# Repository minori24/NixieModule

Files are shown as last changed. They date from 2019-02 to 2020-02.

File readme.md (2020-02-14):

# nix module: miniature nixie tube driver modules

## nix module(仮)
nix moduleはニキシー管の制御に必要な部品を2x4cmの小さな基板に詰め込んだモジュールです。高圧電源の制御や煩雑なダイナミック点灯のコードを考える必要もなく、マイコンとI2Cで接続するだけでニキシー管の制御が可能です。Arduinoライブラリと組み合わせることでシンプルにニキシー管を点灯させることができます。

最大16桁をI2C経由で連結させ、各桁を独立して制御できます。すべての数字でフェードイン・フェードアウト、シャッフルなどのエフェクトが可能です。またRGB LEDによるバックライトもついています。

## Features
- 2x4cm
- I2Cインタフェース(プルアップ抵抗実装済み)
- ハードウェアPWM制御
- RGBバックライト(WS2812B互換 SK6812mini)
- スタティック点灯でシンプルな回路構成

## Arduino Library
ライブラリは[こちら](https://github.com/minori24/Lib_Nixie_Module)にあります。

使用方法は [Getting Started](doc/getting_started.md) および [Library Reference](doc/library_reference.md) を参照して下さい。

## Open Design
回路図、BOM、PCB DesignをこのGitHub Repoで公開しています。KiCadで自由に編集可能です。

回路図(IN-12 module): [Nixie_Module_IN-12_Schematics.pdf](doc/Nixie_Module_IN-12_Schematics.pdf)

PWMドライバはサーボモータの制御によく使われるPCA9685PW、RGB LEDはシリアル接続LEDの小型版なので、Arduino以外のマイコンボードやRaspberry Piによる制御も簡単に行えます。

## Issue
動作に不明点、問題などある場合はぜひ[Issue](https://github.com/minori24/NixieModule/issues)を立てて下さい。

## Project Examples

Nixie Watch (by [@Robo_akira](https://twitter.com/Robo_akira/status/1117429584108982274))

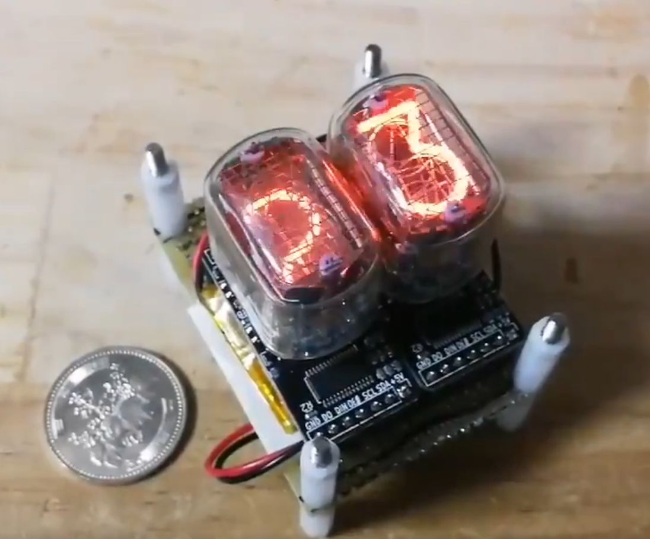
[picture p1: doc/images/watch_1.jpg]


IN-14 Nixie Clock

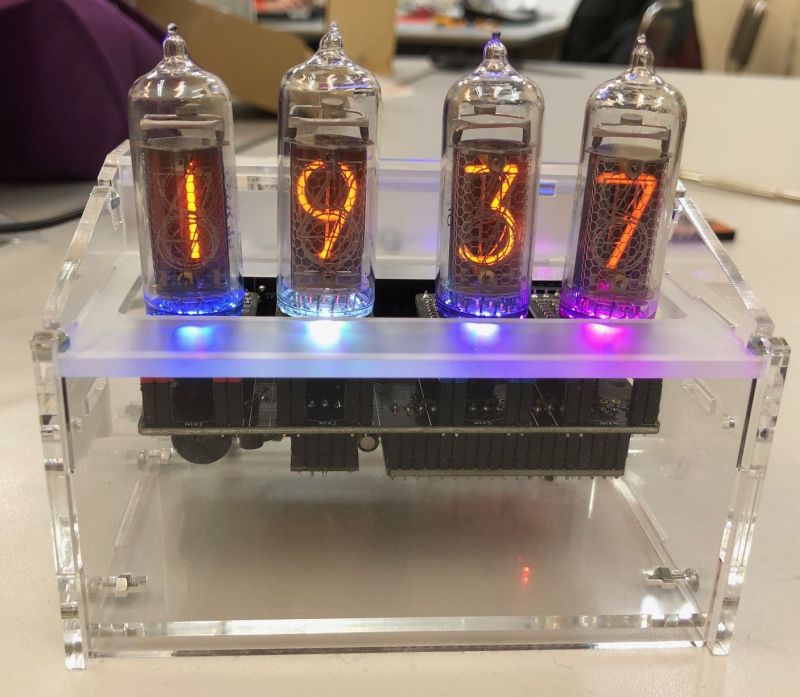
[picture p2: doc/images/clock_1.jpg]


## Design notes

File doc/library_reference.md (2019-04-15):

# Arduino Library Reference

## コンストラクタと初期化

```cpp
NixieModule_IN_12 nix0 = NixieModule_IN_12(uint8_t addr);
NixieModule_IN_14 nix1 = NixieModule_IN_14(uint8_t addr);
```
`uint8_t addr`

モジュール裏のショートジャンパで設定したアドレスを渡します。複数のモジュールを同じバスに接続する場合にアドレスが重複しないよう注意して下さい。

```cpp
void init()
```
モジュールを初期化します。

## 数字の表示
```cpp
void setNumber(uint8_t number, uint8_t step)
```

ニキシー管に表示する数字を設定します。

`uint8_t number`

表示したい数値を指定します。0-9の値です。

`uint8_t step`

クロスフェードやシャッフル表示の場合、現在表示されている数字から新しく設定した数字に切り替わるまでのステップ数を指定します。これらのエフェクトを使用しない場合(transition mode = TMODE_NORMAL)、指定した数値に関わらず常にstep = 1です。

```cpp
void update()
```
`setNumber()` で指定した数字を表示します。stepで指定した回数呼び出すことでクロスフェードやシャッフルのエフェクトをかけながら数字を切り替えます。

```cpp
nix0.setNumber(7, 100); //'7'を表示, 100stepで変化
for (int i=0; i<100; i++){
    nix0.update();
    delay(2);
}
```
数字が切り替わるスピードはstepの回数と `update()` を呼び出す間隔で決まります。`delay()`を入れて適宜調整して下さい。

## エフェクト設定
```cpp
void setTransitionMode(uint8_t mode)
```
`uint8_t mode`

数字の切り替えで使用するエフェクトを指定します。

`TMODE_NORMAL` : エフェクト無し

`TMODE_FADE` : クロスフェード

`TMODE_SHUFFLE` : シャッフル

## 明るさの調整
```cpp
void setBrightness(uint8_t b)
```

`float b`

明るさを 0 - 1.0 の間で指定します。

## I2C Command Protocol
ライブラリを使用せず直接制御する場合のI2CコマンドはPCA9685PWのデータシートを参照して下さい。

## RGB LED
LEDの制御にはAdafruit NeoPixel Library等のライブラリが使えます。

Adafruit Neopixel Library on GitHub

https://github.com/adafruit/Adafruit_NeoPixel

いまさらNeo Pixelまとめ - 滴了庵日録

https://lipoyang.hatenablog.com/entry/20180106/p1

## Future Candidates

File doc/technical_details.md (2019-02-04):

# nix module IN-12 Technical Details

## Specs
Compatible tube
 - IN-12A/B, IN-15

Driven Cathodes
 - 10 Digits + 1 Dot

Backlight
 - RGB LED Backlight

Dimension
 - 20mm x 40mm (Board only)

Supply Voltage
 - 5V

Nixie Tube Cathode Voltage
 - 180V

 I2C Max Speed
  - 400kHz

## I2C Command Protocol
nix modules is using PCA9685PW for I2C interface and to control PWM signals. Please refer datasheet for technical details.

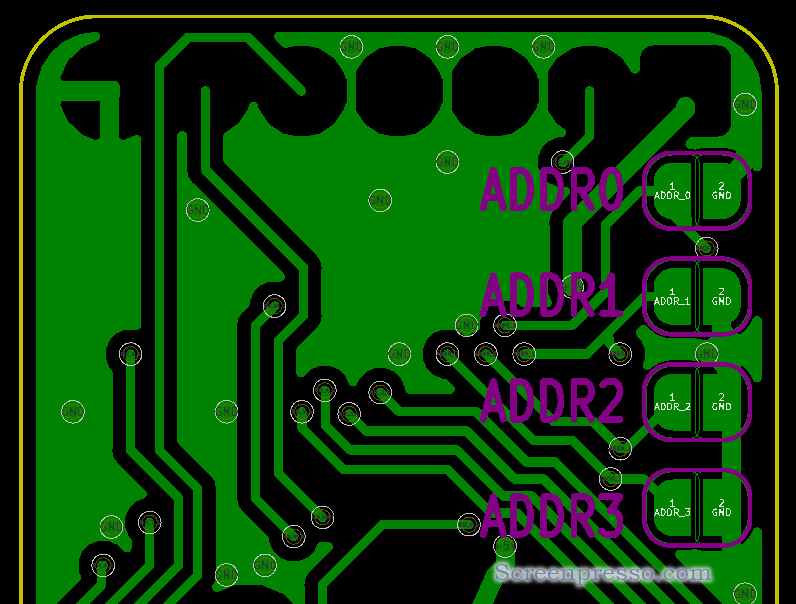
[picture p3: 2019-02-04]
doc/images/addr.png

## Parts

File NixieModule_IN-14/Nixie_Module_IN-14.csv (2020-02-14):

Reference | Quantity | Value | Footprint | Datasheet
C1 | 1 | 47u | C_SMD:C_0603
C2 | 1 | 100n | C_SMD:C_0603
C3 | 1 | 4.7u | C_SMD:C_0603
J1 | 1 | Conn_01x07_Female |  | ~
J2 | 1 | Conn_01x02_Female |  | ~
J3 | 1 | CONN_01X02 | Pin_Headers:Pin_Header_Straight_1x02_Pitch2.54mm
JP1 JP2 JP3 JP4 | 4 | SolderJumper_2_Open | Jumper:SolderJumper-2_P1.3mm_Open_RoundedPad1.0x1.5mm
N1 | 1 | IN-14 | russian-nixies:russian-nixies-IN-14
Q1 Q3 Q5 Q7 Q9 Q2 Q4 Q6 Q8 Q10 | 10 | Q_NPN_BEC | TO_SOT:SOT-23
R1 | 1 | 47k | R_SMD:R_0603
R3 R5 R7 R9 R11 R4 R6 R8 R10 R12 R14 R15 R16 R17 R2 R18 R19 | 17 | 10k | R_SMD:R_0603
U1 | 1 | SK6812mini
U3 | 1 | PCA9685PW | Housings_SSOP:TSSOP-28_4.4x9.7mm_Pitch0.65mm | http://www.nxp.com/documents/data_sheet/PCA9685.pdf

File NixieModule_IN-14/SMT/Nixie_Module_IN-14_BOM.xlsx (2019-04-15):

Parts | Value | Package | Qty
U3 | PCA9685PW | TSSOP-28 | 1
U1 | SK6812MINI | SK6812MINI_3535 | 1
C2 | 100nF | C_0603 | 1
C1, C3 | 4.7uF | C_0603 | 2
Q9, Q7, Q2, Q4, Q6, Q3, Q8, Q1, Q5, Q10 | MMBTA42LT1G | SOT-23 | 10
R12, R3, R5, R7, R9, R11, R4, R6, R8, R10, R2, R17, R16, R18, R19, R15, R14 | 10k | R_0603 | 17
R1 | 47k | R_0603 | 1

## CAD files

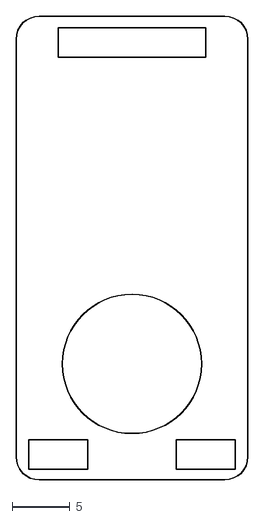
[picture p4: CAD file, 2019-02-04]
NixieModule_IN-12/outline_drawings.dxf
20.0 x 40.0

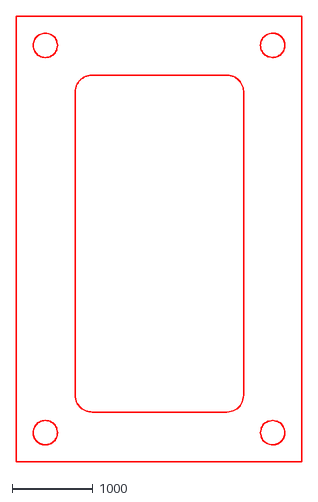
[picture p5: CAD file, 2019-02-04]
NixieModule_IN-12/SMT/outline.dxf
3530.7 x 5509.8

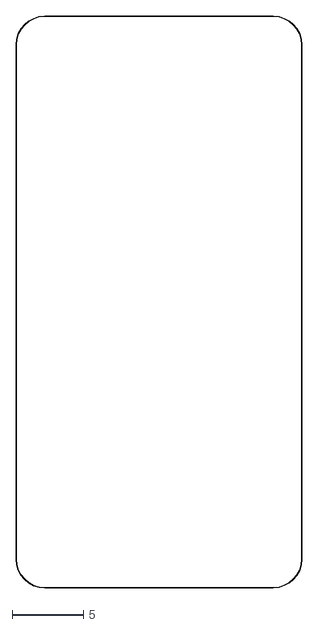
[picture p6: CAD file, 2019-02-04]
NixieModule_IN-12/outline_cut.dxf
20.0 x 40.0

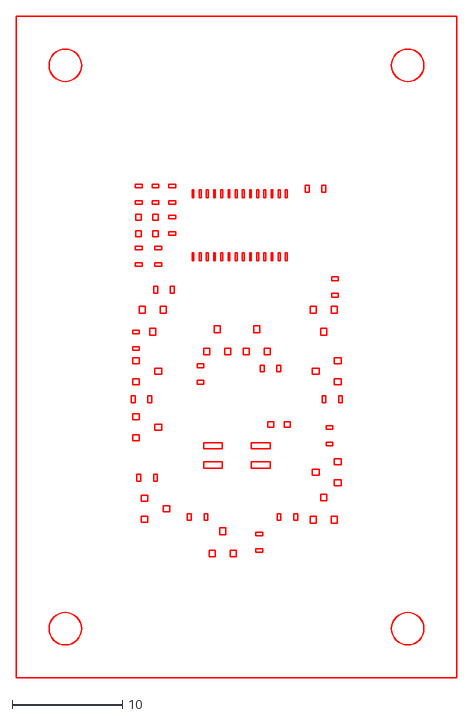
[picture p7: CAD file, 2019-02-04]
NixieModule_IN-12/SMT/Stencil.dxf
39.9 x 59.9

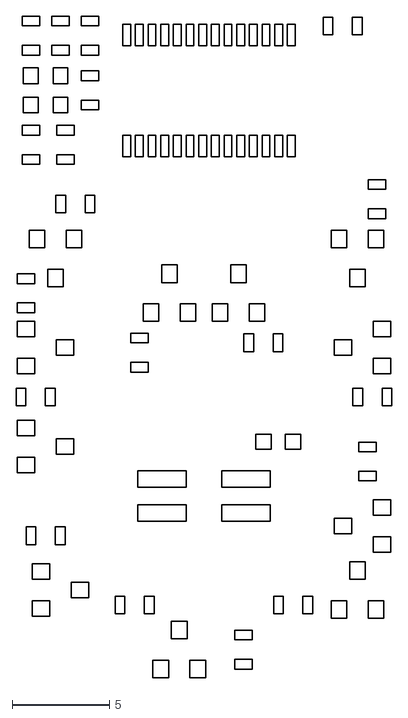
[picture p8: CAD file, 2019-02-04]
NixieModule_IN-12/SMT/stencil_r14.dxf
19.3 x 34.0

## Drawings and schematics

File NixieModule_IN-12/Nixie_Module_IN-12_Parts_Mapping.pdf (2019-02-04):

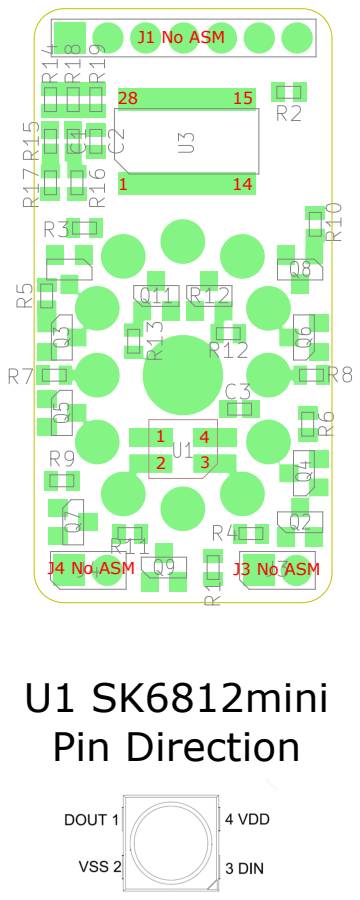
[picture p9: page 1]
U1 SK6812mini Pin Direction; J4 No ASM; J3 No ASM; J1 No ASM

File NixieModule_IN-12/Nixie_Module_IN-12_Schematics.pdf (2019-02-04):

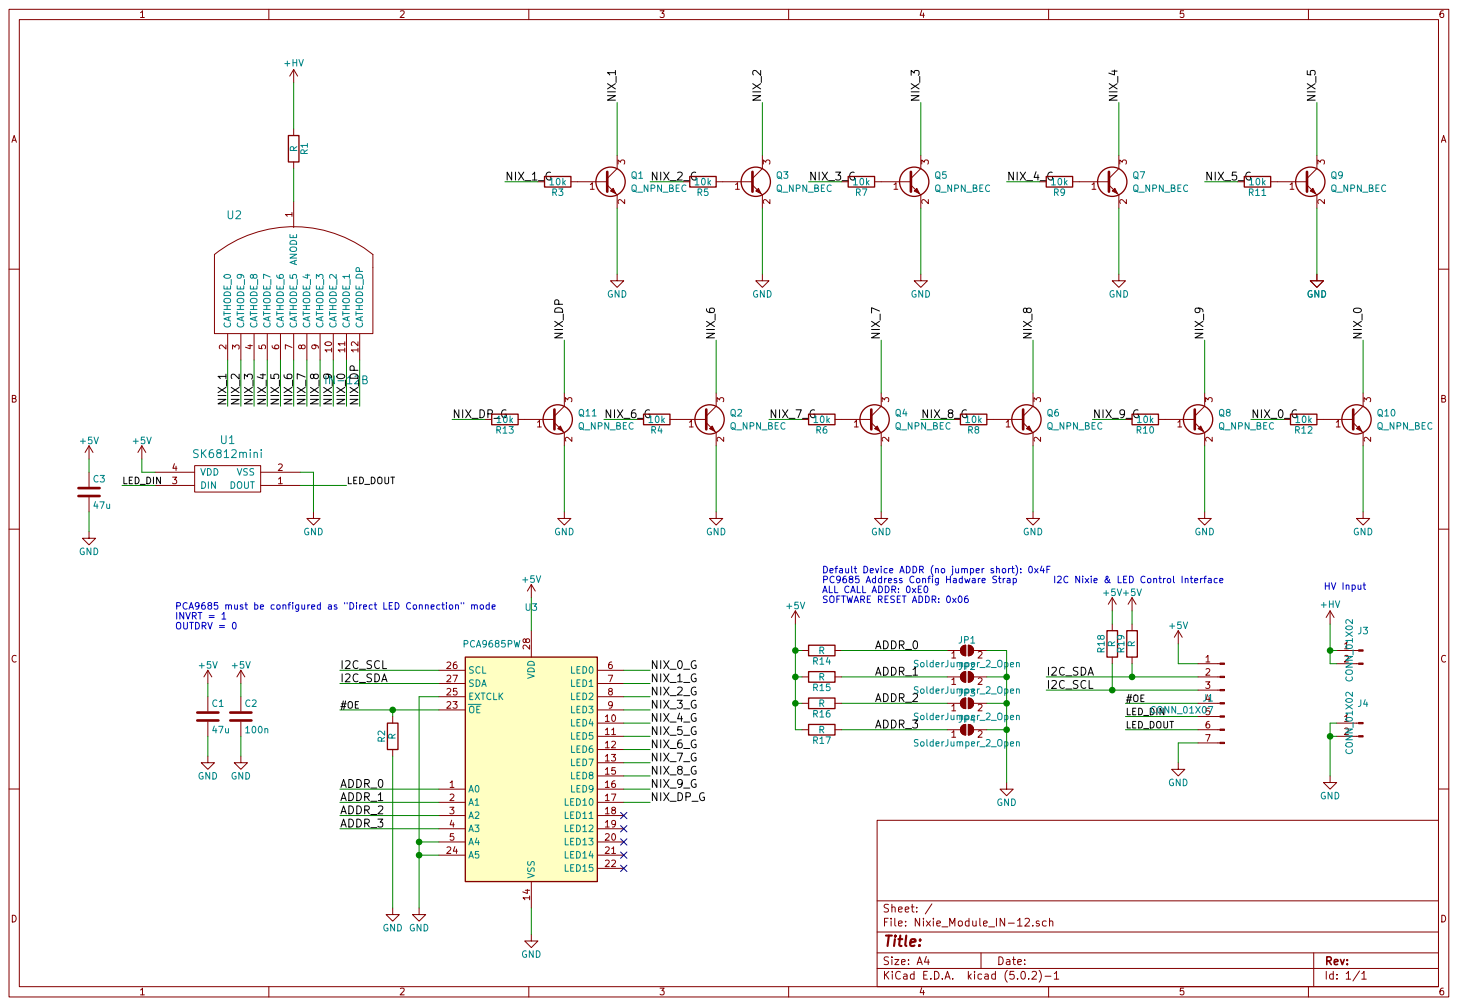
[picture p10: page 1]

PC9685 Address Config Hadware Strap ALL CALL ADDR: 0xE0 SOFTWARE RESET ADDR: 0x06 R15 R

PCA9685 must be configured as "Direct LED Connection" mode

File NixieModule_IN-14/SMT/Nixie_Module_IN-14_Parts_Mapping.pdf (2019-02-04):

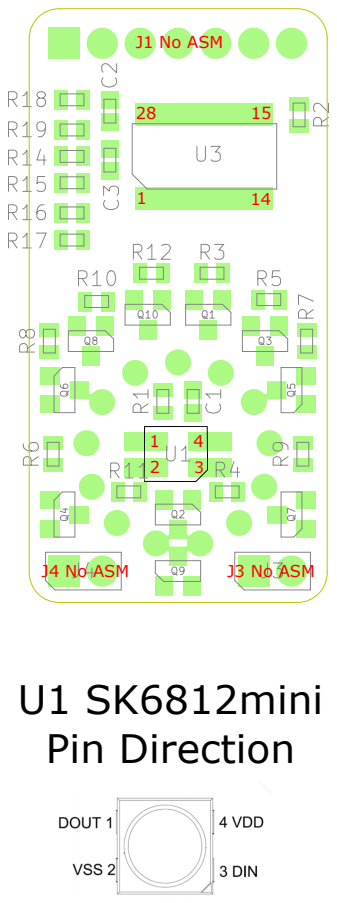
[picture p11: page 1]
U1 SK6812mini Pin Direction; J1 No ASM; J4 No ASM; J3 No ASM

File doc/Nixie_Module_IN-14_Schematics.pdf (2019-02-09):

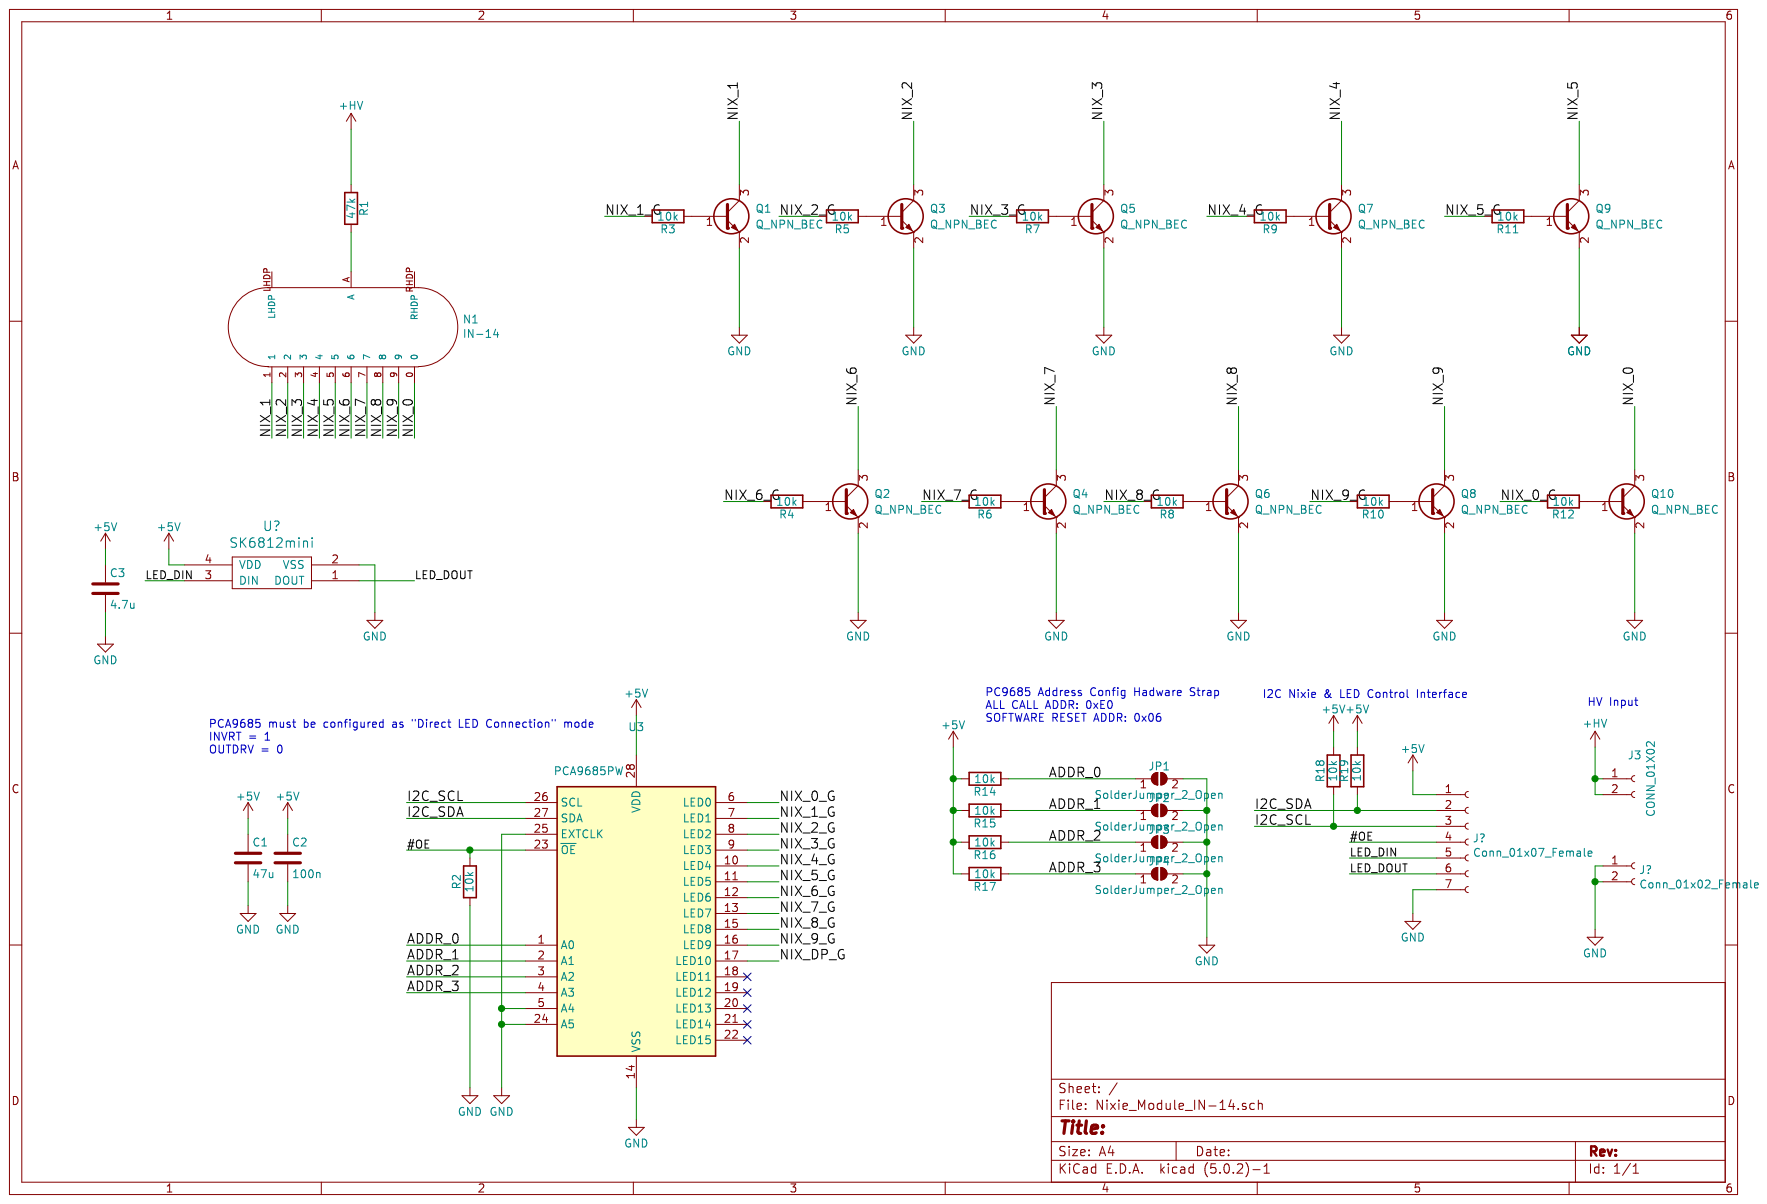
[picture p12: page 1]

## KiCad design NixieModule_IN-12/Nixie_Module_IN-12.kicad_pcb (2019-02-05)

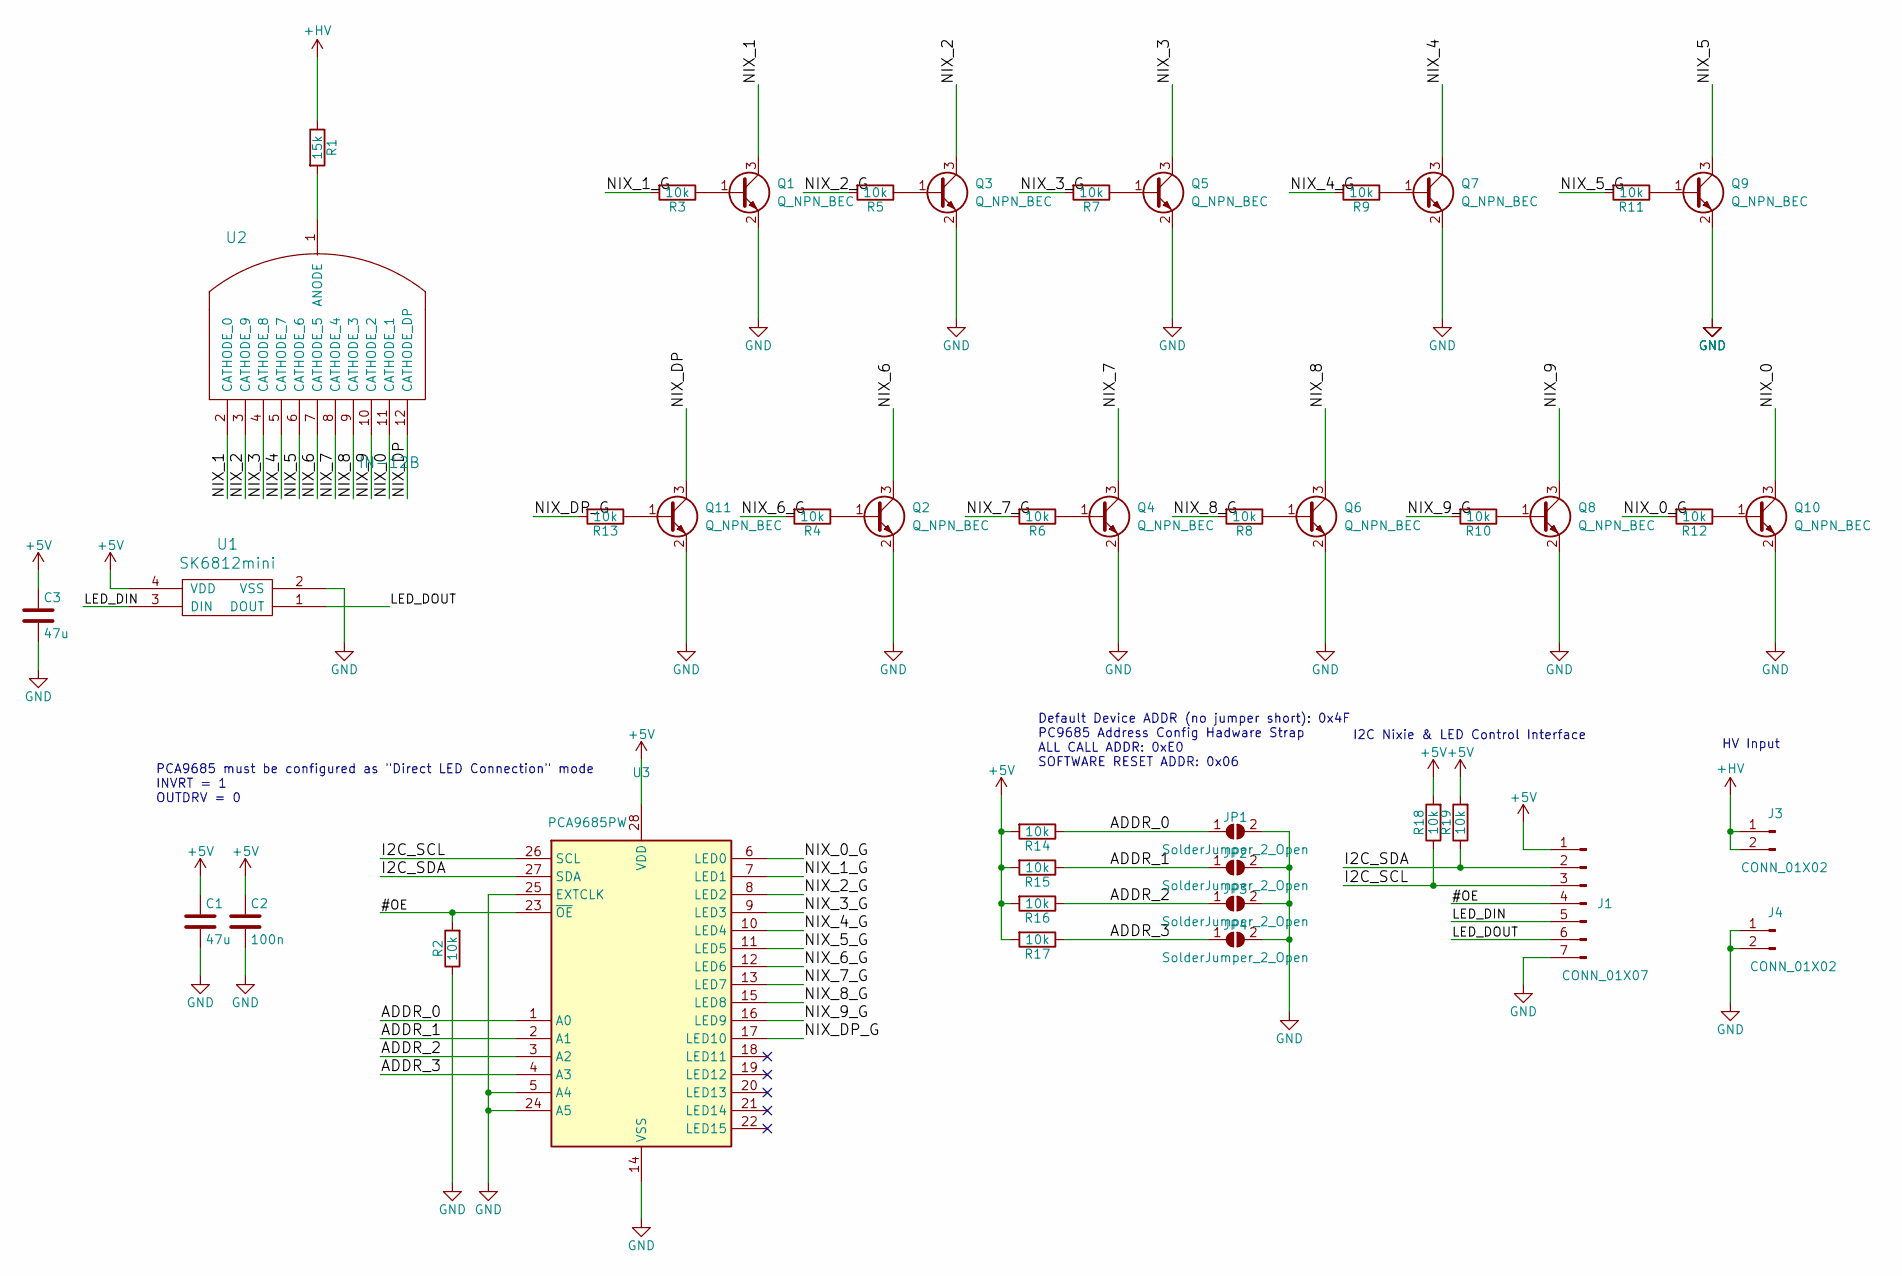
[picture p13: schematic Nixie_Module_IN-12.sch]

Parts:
C1, C3: 47u; C_0603
C2: 100n; C_0603
J1: CONN_01X07; Pin_Header_Straight_1x07_Pitch2.54mm
J3, J4: CONN_01X02; Pin_Header_Straight_1x02_Pitch2.54mm
JP1, JP2, JP3, JP4: SolderJumper_2_Open; SolderJumper-2_P1.3mm_Open_RoundedPad1.0x1.5mm
Q1, Q2, Q3, Q4, Q5, Q6, Q7, Q8, Q9, Q10, Q11: Q_NPN_BEC; SOT-23
R1: 15k; R_0603
R2, R3, R4, R5, R6, R7, R8, R9, R10, R11, R12, R13, R14, R15, R16, R17, R18, R19: 10k; R_0603
U1: SK6812mini; SK6812MINI
U2: IN-12B
U3: PCA9685PW; TSSOP-28_4.4x9.7mm_Pitch0.65mm

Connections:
+5V: C1.1, C2.1, C3.1, J1.1, R14.2, R15.2, R16.2, R17.2, R18.2, R19.2, U1.4 (VDD), U3.28 (VDD)
+HV: J3.1, J3.2, R1.1
/#OE: J1.4, R2.2, U3.23 (~OE)
/ADDR_0: JP1.1 (A), R14.1, U3.1 (A0)
/ADDR_1: JP2.1 (A), R15.1, U3.2 (A1)
/ADDR_2: JP3.1 (A), R16.1, U3.3 (A2)
/ADDR_3: JP4.1 (A), R17.1, U3.4 (A3)
/I2C_SCL: J1.3, R18.1, U3.26 (SCL)
/I2C_SDA: J1.2, R19.1, U3.27 (SDA)
/LED_DIN: J1.5, U1.3 (DIN)
/LED_DOUT: J1.6, U1.1 (DOUT)
/NIX_0: Q10.3 (C), U2.11 (CATHODE_1)
/NIX_0_G: R12.2, U3.6 (LED0)
/NIX_1: Q1.3 (C), U2.2 (CATHODE_0)
/NIX_1_G: R3.2, U3.7 (LED1)
/NIX_2: Q3.3 (C), U2.3 (CATHODE_9)
/NIX_2_G: R5.2, U3.8 (LED2)
/NIX_3: Q5.3 (C), U2.4 (CATHODE_8)
/NIX_3_G: R7.2, U3.9 (LED3)
/NIX_4: Q7.3 (C), U2.5 (CATHODE_7)
/NIX_4_G: R9.2, U3.10 (LED4)
/NIX_5: Q9.3 (C), U2.6 (CATHODE_6)
/NIX_5_G: R11.2, U3.11 (LED5)
/NIX_6: Q2.3 (C), U2.7 (CATHODE_5)
/NIX_6_G: R4.2, U3.12 (LED6)
/NIX_7: Q4.3 (C), U2.8 (CATHODE_4)
/NIX_7_G: R6.2, U3.13 (LED7)
/NIX_8: Q6.3 (C), U2.9 (CATHODE_3)
/NIX_8_G: R8.2, U3.15 (LED8)
/NIX_9: Q8.3 (C), U2.10 (CATHODE_2)
/NIX_9_G: R10.2, U3.16 (LED9)
/NIX_DP: Q11.3 (C), U2.12 (CATHODE_DP)
/NIX_DP_G: R13.2, U3.17 (LED10)
GND: C1.2, C2.2, C3.2, J1.7, J4.1, J4.2, JP1.2 (B), JP2.2 (B), JP3.2 (B), JP4.2 (B), Q1.2 (E), Q2.2 (E), Q3.2 (E), Q4.2 (E), Q5.2 (E), Q6.2 (E), Q7.2 (E), Q8.2 (E), Q9.2 (E), Q10.2 (E), Q11.2 (E), R2.1, U1.2 (VSS), U3.5 (A4), U3.14 (VSS), U3.24 (A5), U3.25 (EXTCLK)
unnamed: Q1.1 (B), R3.1
unnamed: Q2.1 (B), R4.1
unnamed: Q3.1 (B), R5.1
unnamed: Q4.1 (B), R6.1
unnamed: Q5.1 (B), R7.1
unnamed: Q6.1 (B), R8.1
unnamed: Q7.1 (B), R9.1
unnamed: Q8.1 (B), R10.1
unnamed: Q9.1 (B), R11.1
unnamed: Q10.1 (B), R12.1
unnamed: Q11.1 (B), R13.1
unnamed: R1.2, U2.1 (ANODE)

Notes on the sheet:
Default Device ADDR (no jumper short): 0x4F PC9685 Address Config Hadware Strap ALL CALL ADDR: 0xE0 SOFTWARE RESET ADDR: 0x06
PCA9685 must be configured as "Direct LED Connection" mode INVRT = 1 OUTDRV = 0
I2C Nixie & LED Control Interface
HV Input

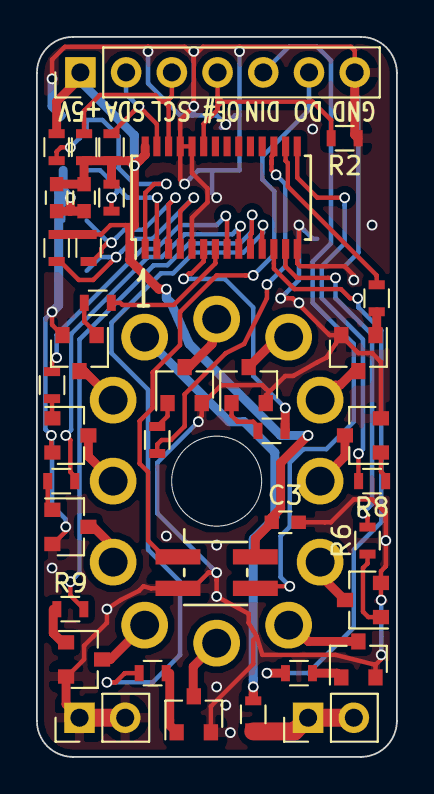
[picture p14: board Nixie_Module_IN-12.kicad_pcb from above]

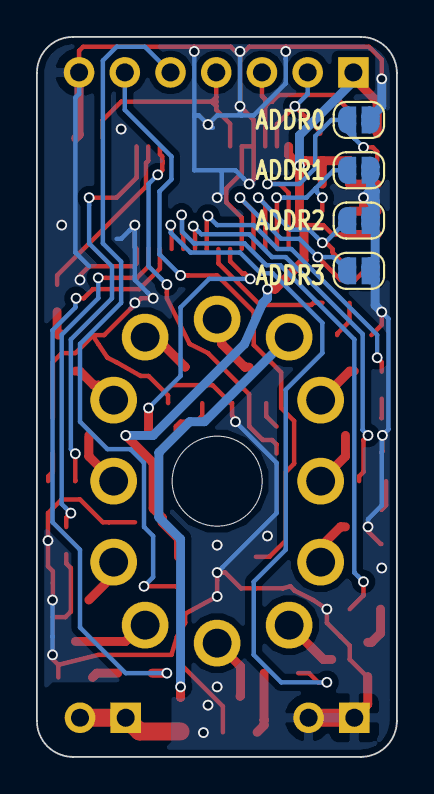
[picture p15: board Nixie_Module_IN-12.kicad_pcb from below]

Board: 2 copper layers, 20.0 x 40.0 mm, 43 parts (4 on the bottom side), 46 nets.

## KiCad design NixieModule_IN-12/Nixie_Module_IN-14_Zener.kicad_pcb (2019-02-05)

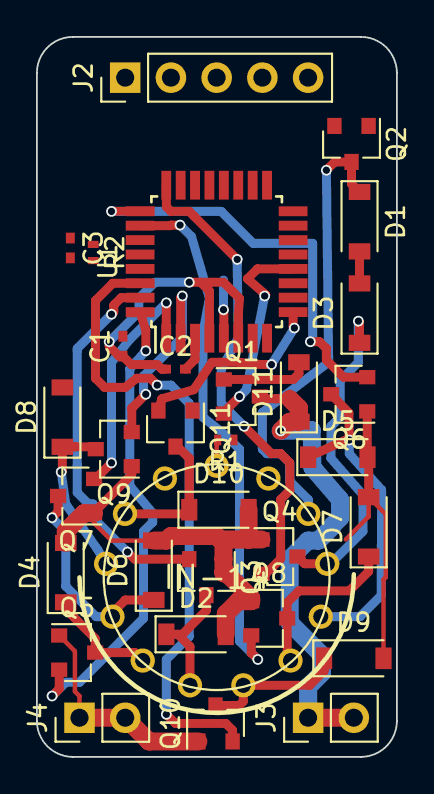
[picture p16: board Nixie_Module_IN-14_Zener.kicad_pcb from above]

Board: 2 copper layers, 20.0 x 40.0 mm, 33 parts (1 on the bottom side), 34 nets.

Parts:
C1: 47u; C_0402_NoSilk
C2, C3: 100n; C_0402_NoSilk
D1, D2, D3, D4, D5, D6, D7, D8, D9, D10, D11: D_Zener; D_SOD-123
J1: CONN_01X04; PinHead_SMD_1x4
J2: CONN_01X05; Pin_Header_Straight_1x05_Pitch2.54mm
J3, J4: CONN_01X02; Pin_Header_Straight_1x02_Pitch2.54mm
N1: IN-14; russian-nixies-IN-14
Q1, Q2, Q3, Q4, Q5, Q6, Q7, Q8, Q9, Q10, Q11: Q_NMOS_SGD; SOT-23
R1, R2: R; R_0402_NoSilk
U1: ATMEGA48-20AU; TQFP-32_7x7mm_Pitch0.8mm

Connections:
+5V: C1.1, C2.1, J2.1, R2.1, U1.4, U1.6, U1.18
+HV: D11.1, J3.1, J3.2, Q1.3
/#RESET: C3.2, R2.2, U1.29
/I2C_SCL: J2.4, U1.28
/I2C_SDA: J2.3, U1.27
/NIX_0: D10.1, N1.0, Q11.3
/NIX_0_G: Q11.2, U1.9
/NIX_1: D1.1, N1.1, Q2.3
/NIX_1_G: Q2.2, U1.23
/NIX_2: D3.1, N1.2, Q4.3
/NIX_2_G: Q4.2, U1.24
/NIX_3: D5.1, N1.3, Q6.3
/NIX_3_G: Q6.2, U1.25
/NIX_4: D7.1, N1.4, Q8.3
/NIX_4_G: Q8.2, U1.26
/NIX_5: D9.1, N1.5, Q10.3
/NIX_5_G: Q10.2, U1.30
/NIX_6: D2.1, N1.6, Q3.3
/NIX_6_G: Q3.2, U1.31
/NIX_7: D4.1, N1.7, Q5.3
/NIX_7_G: Q5.2, U1.32
/NIX_8: D6.1, N1.8, Q7.3
/NIX_8_G: Q7.2, U1.1
/NIX_9: D8.1, N1.9, Q9.3
/NIX_9_G: Q9.2, U1.2
/NIX_ANODE: Q1.2, U1.12
/SPI_#SS: J1.1, U1.14
/SPI_MISO: J1.3, U1.16
/SPI_MOSI: J1.2, U1.15
/SPI_SCK: J1.4, U1.17
GND: C1.2, C2.2, D1.2, D2.2, D3.2, D4.2, D5.2, D6.2, D7.2, D8.2, D9.2, D10.2, J2.5, J4.1, J4.2, Q2.1, Q3.1, Q4.1, Q5.1, Q6.1, Q7.1, Q8.1, Q9.1, Q10.1, Q11.1, U1.3, U1.5, U1.21
unnamed: C3.1, J2.2
unnamed: D11.2, Q1.1, R1.1
unnamed: N1.A, R1.2

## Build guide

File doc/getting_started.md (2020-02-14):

# Getting Started with nix modules

## 必要なもの

### ニキシー管

ニキシー管 - Wikipedia

https://ja.wikipedia.org/wiki/%E3%83%8B%E3%82%AD%E3%82%B7%E3%83%BC%E7%AE%A1

ニキシー管は生産国や年代によって多くの種類がありますが、そのほぼ全てが数十年前に生産終了となっています。現在流通しているのはデッドストック品や中古品です。
nix moduleは**IN-12**および**IN-14**と呼ばれるニキシー管に対応しています。これらは現在でも比較的手に入りやすく、価格も手頃なニキシー管です。

IN-14はサイドビュー型(管の横から数字を表示)、IN-12はトップビュー型(管の上面から表示)の形状です。IN-12にはIN-12A/IN-12Bという種類があり、ドットの有無が異なります。
また、IN-15A/Bのように数字ではなく記号を表示するニキシー管もあります。こちらはIN-12とピン互換のため、IN-12版nix moduleで点灯可能です(Arduinoライブラリは未対応)。

### 高圧電源
ニキシー管を点灯させるには150 - 200V程度の直流電源が必要です。多くの場合は昇圧モジュールを使いACアダプタや電池などの低圧電源を昇圧して供給します。高圧電源キットの他、MC34062を使ったDC-DCコンバータなどの作例も多くあります。

[参考]

ニキシー管 電源 - Google検索

https://www.google.com/search?q=%E3%83%8B%E3%82%AD%E3%82%B7%E3%83%BC%E7%AE%A1+%E9%9B%BB%E6%BA%90

ニキシー管用小型高圧電源キット

https://www.kadenken.com/shopdetail/000000000727/

昇圧して高電圧(DC140V~)を作る

https://qiita.com/hotchpotch/items/b9ec56266a5592cc3317

## ニキシー管のハンダ付け
moduleにニキシー管をハンダ付けします。IN-14はニキシー管の裏側に1番ピンを示す矢印があります。moduleの1番ピンに合うように差し込んで下さい。IN-14は下図の上側がニキシー管の正面になります。

また、IN-12はソケットピンを使用するとニキシー管の交換が楽になります。
ソケットピンは最初にニキシー管の足にピンを挿してからmoduleに取り付けて下さい。

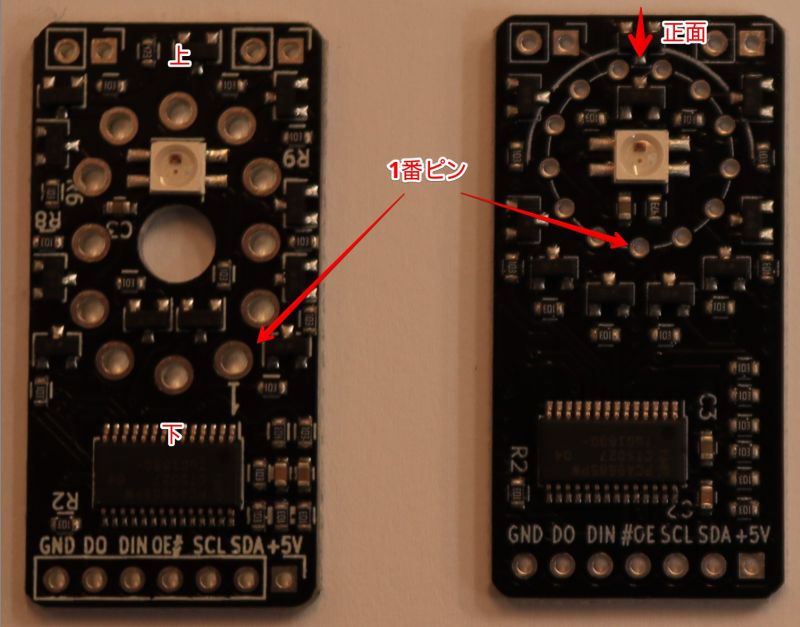
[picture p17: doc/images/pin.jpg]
Pin


## Arduinoライブラリ
[Library Reference](library_reference.md)参照

## 配線
ArduinoのI2C PinおよびLED制御用のDigital pinに接続します。
電源は5VとGNDをArduinoに接続、module上部のピンに高圧電源(170 - 180V)の出力とそのGNDを接続します。

Maker Faire等のイベントで電源モジュールをセットで購入された場合、5Vもしくは12Vから170Vへ昇圧するモジュールが同梱されています。高電圧が出力されるため非常に危険です。配線は確実に電源を落とした状態で行い、通電中のモジュールには絶対に触らないようご注意ください。

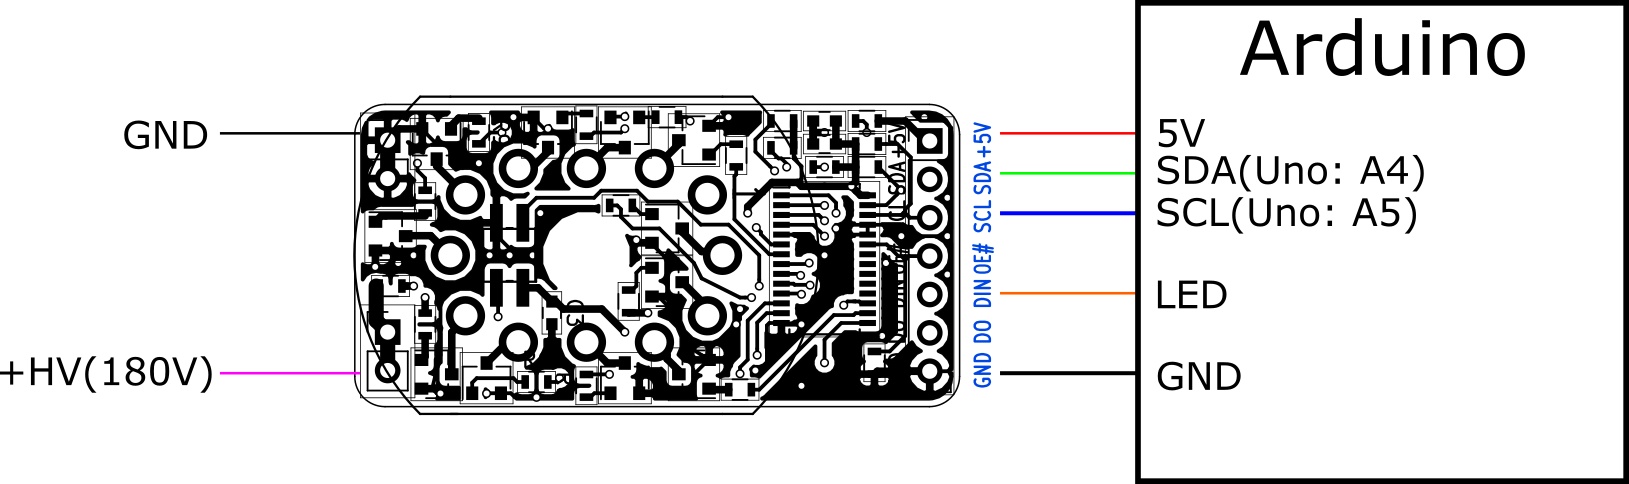
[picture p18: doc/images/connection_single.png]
Connection


## テスト
Arduinoにサンプルコードを書き込み、点灯をチェックします。

## nix moduleのI2Cアドレス設定
複数のnix moduleを1つのI2Cバスで連結させる場合、モジュール裏側のジャンパをショートさせることでそれぞれ重複しないI2Cアドレスを設定する必要があります
(オープン = '1'　ショート = '0')。

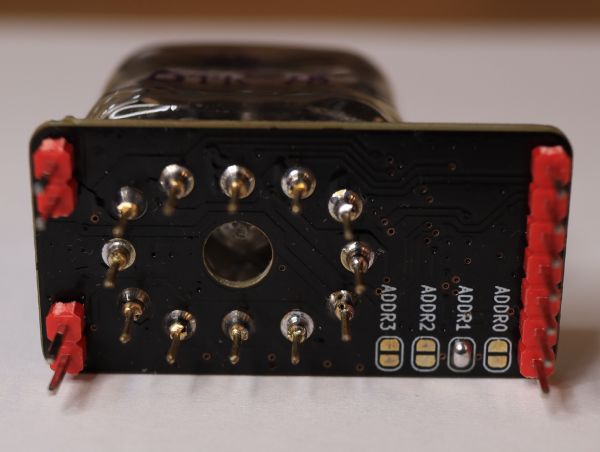
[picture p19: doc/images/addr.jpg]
ADDR Short Jumper


nix moduleの7bitアドレスはデフォルト(ジャンパのショート無し)で**0x4F**です。アドレス下位4bitをジャンパで設定します。

module 0: アドレス = 0x4F (1111, ジャンパショート無し)

module 1: アドレス = 0x4E (1110, ADDR0をショート)

module 2: アドレス = 0x4D (1101, ADDR1をショート)

module 3: アドレス = 0x4C (1100, ADDR1, ADDR0をショート)

etc...

ここで設定したアドレスをArduinoのコードに書き込みます。

```cpp
#include "libNixieModule.h"

#include <Wire.h>
#define ADDR0 0x4F //モジュールのI2Cアドレス
#define ADDR1 0x4E
#define ADDR2 0x4D
#define ADDR3 0x4C

NixieModule_IN_12 nix0 = NixieModule_IN_12(ADDR0);
NixieModule_IN_12 nix1 = NixieModule_IN_12(ADDR1);
NixieModule_IN_12 nix2 = NixieModule_IN_12(ADDR2);
NixieModule_IN_12 nix3 = NixieModule_IN_12(ADDR3);

void setup() { 

  nix0.init();
  nix1.init();
  nix2.init();
  nix3.init();
    .
    .
    .
}

    .
    .
    .

```

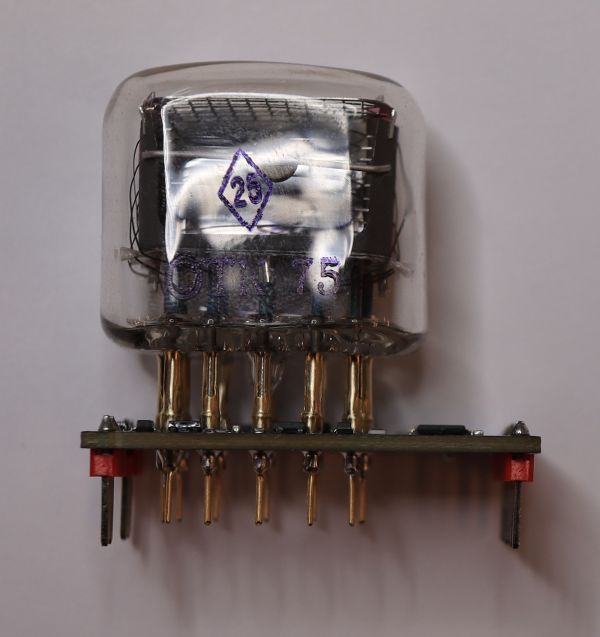
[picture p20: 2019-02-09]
doc/images/socket_solder.jpg

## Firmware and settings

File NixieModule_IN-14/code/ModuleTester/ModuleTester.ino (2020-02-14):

#include "libNixieModule.h"
#include <Adafruit_NeoPixel.h>
#include <Wire.h>

#define ADDR0 0x4F
#define ADDR1 0x4D

#define NIX_DOT_A A0
#define NIX_DOT_B A1
#define PIN_LED 6

NixieModule_IN_14 nix0 = NixieModule_IN_14(ADDR0);

Adafruit_NeoPixel strip = Adafruit_NeoPixel(2, PIN_LED, NEO_GRB + NEO_KHZ800);

void setup() {
  // put your setup code here, to run once:
  Serial.begin(9600);
  Serial.println("nix module IN-14 Single Tube Demo");
  nix0.init();

  nix0.setTransitionMode(TMODE_NORMAL);
  strip.begin();
  strip.show(); // Initialize all pixels to 'off'
}

void loop() {
  // put your main code here, to run repeatedly:
  uint8_t step = 100;
  Serial.println("Normal transition mode");

  step = 100;
  nix0.setTransitionMode(TMODE_FADE);
  
  for(int i=0; i<10; i++){
    Serial.println(i);
    nix0.setNumber(i, step);

    for(int j=0; j<step; j++){
      nix0.update();

      delay(2);
    }
    delay(500);
  }

  theaterChase(strip.Color(127, 127, 127), 50); // White
  theaterChase(strip.Color(127, 0, 0), 50); // Red
  theaterChase(strip.Color(0, 0, 127), 50); // Blue

  delay(1000);

}

//Theatre-style crawling lights.
void theaterChase(uint32_t c, uint8_t wait) {
  for (int j=0; j<10; j++) {  //do 10 cycles of chasing
    for (int q=0; q < 3; q++) {
      for (uint16_t i=0; i < strip.numPixels(); i=i+3) {
        strip.setPixelColor(i+q, c);    //turn every third pixel on
      }
      strip.show();

      delay(wait);

      for (uint16_t i=0; i < strip.numPixels(); i=i+3) {
        strip.setPixelColor(i+q, 0);        //turn every third pixel off
      }
    }
  }
}

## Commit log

2019-02-05 Update documentation
    [Nixie_Module_IN-12-bottom-pos.csv, Nixie_Module_IN-12-top-pos.csv, Nixie_Module_IN-12.gbl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]
2020-02-14 Document update
    [Nixie_Module_IN-14.csv, Nixie_Module_IN-14.sch]
